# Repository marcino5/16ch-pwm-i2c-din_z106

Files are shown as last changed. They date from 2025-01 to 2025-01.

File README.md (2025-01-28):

# PCB 16xPWM i2c
This repository contains KiCAD files. This is an expansion module containing 16 PWM 12-24V outputs. The circuit consists of 16 N-Channel MOSFETs with a load capacity of 10A per channel controlled by a 12-bit LED controller PCA9685PW with an I2C interface. The circuit is not adapted to the maximum current, and for higher currents it is necessary to tin the exposed plus path. In my home configuration with ESPHome it works with 4 meter LED strips per channel and I did not observe any heating of the paths.

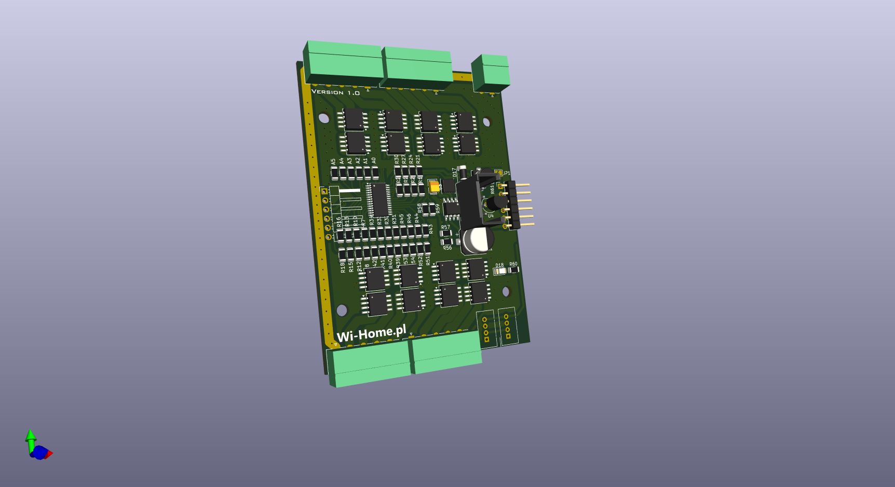
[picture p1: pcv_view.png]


The PCB is designed to fit in a commonly available DIN rail housing.

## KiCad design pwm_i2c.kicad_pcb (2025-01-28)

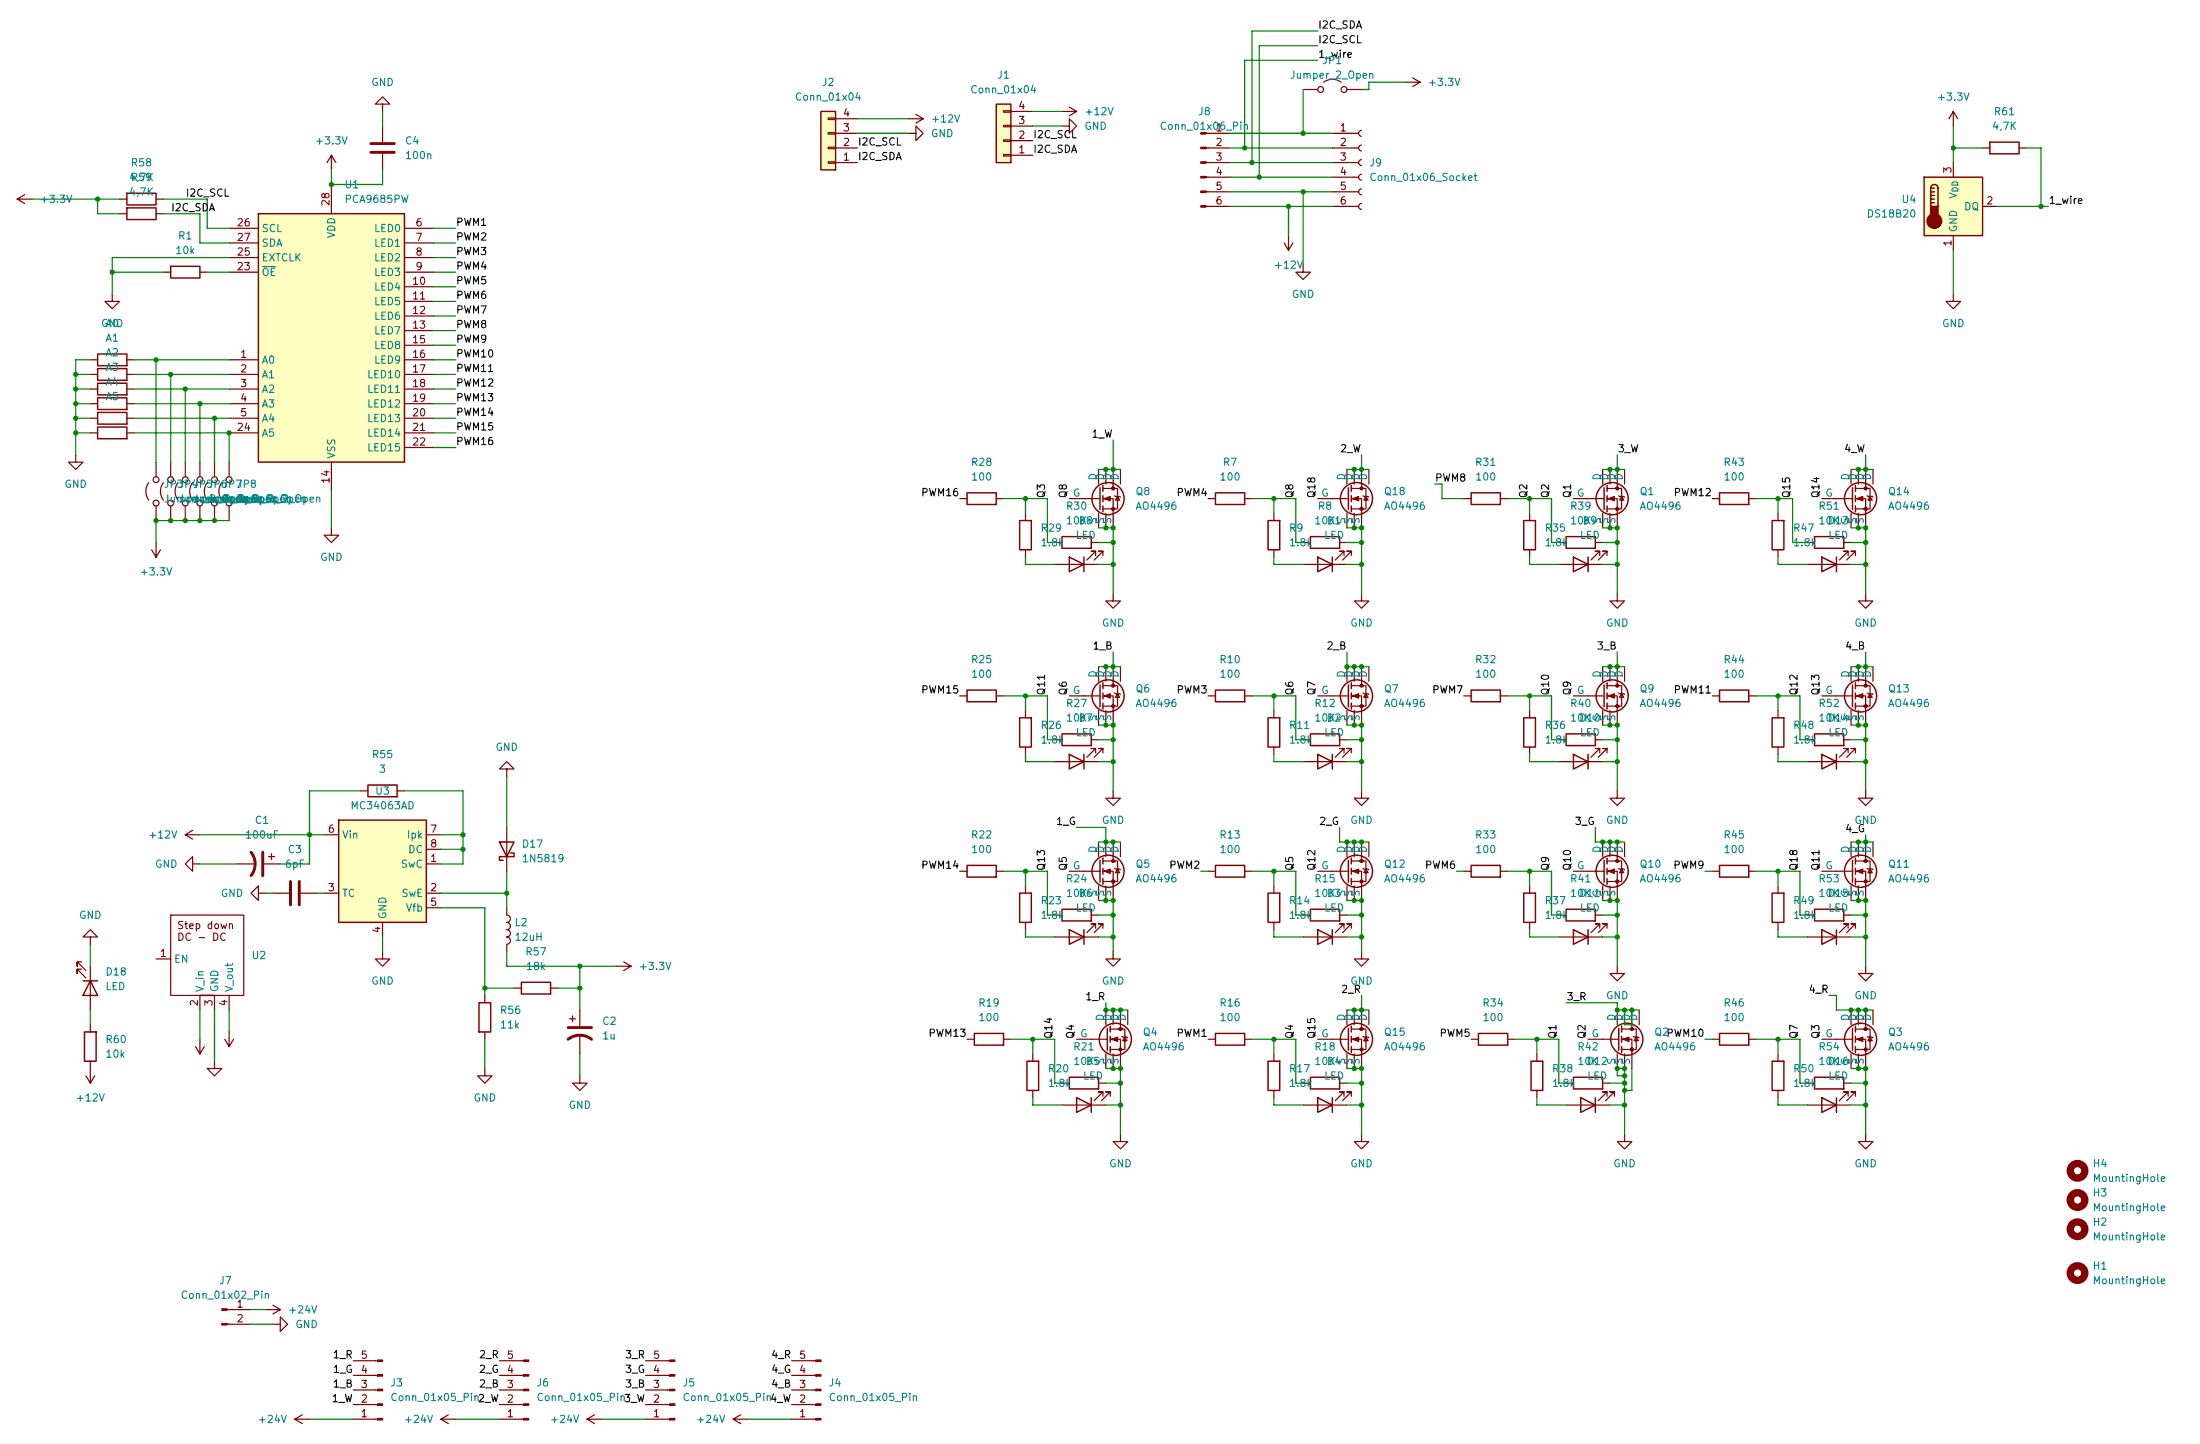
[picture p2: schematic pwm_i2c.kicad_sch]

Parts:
A0, A1, A2, A3, A4, A5: R_1206_3216Metric
C1: 100uF; CP_Elec_8x6.9
C2: 1u; CP_Elec_5x5.3
C3: 6pF; CP_EIA-3528-15_AVX-H
C4: 100n; C_1206_3216Metric_Pad1.33x1.80mm_HandSolder
D1, D2, D3, D4, D5, D6, D7, D8, D9, D10, D11, D12, D13, D14, D15, D16: LED; LED_1206_3216Metric
D17: 1N5819; D_MELF
D18: LED; LED_1206_3216Metric_Pad1.42x1.75mm_HandSolder
H1, H2, H3, H4: MountingHole; MountingHole_3.2mm_M3_ISO7380
J1, J2: Conn_01x04; NS-Tech_Grove_1x04_P2mm_Vertical
J3, J4, J5, J6: Conn_01x05_Pin; PhoenixContact_MC_1,5_5-G-3.81_1x05_P3.81mm_Horizontal
J7: Conn_01x02_Pin; PhoenixContact_MC_1,5_2-G-3.81_1x02_P3.81mm_Horizontal
J8: Conn_01x06_Pin; PinHeader_1x06_P2.54mm_Horizontal
J9: Conn_01x06_Socket; PinHeader_1x06_P2.54mm_Horizontal
JP1, JP3, JP4, JP5, JP6, JP7, JP8: Jumper_2_Open; SolderJumper-2_P1.3mm_Open_TrianglePad1.0x1.5mm
L2: 12uH; L_Changjiang_FNR4010S
Q1, Q2, Q3, Q4, Q5, Q6, Q7, Q8, Q9, Q10, Q11, Q12, Q13, Q14, Q15, Q18: AO4496; SO-8_5.3x6.2mm_P1.27mm
R1, R60: 10k; R_1206_3216Metric
R7, R10, R13, R16, R19, R22, R25, R28, R31, R32, R33, R34, R43, R44, R45, R46: 100; R_1206_3216Metric
R8, R12, R15, R18, R21, R24, R27, R30, R39, R40, R41, R42, R51, R52, R53, R54: 10K; R_1206_3216Metric
R9, R11, R14, R17, R20, R23, R29, R35, R36, R37, R38, R47, R48, R49, R50: 1.8k; R_1206_3216Metric
R26: 1.8k; R_1206_3216Metric_Pad1.30x1.75mm_HandSolder
R55: 3; R_1206_3216Metric
R56: 11k; R_1206_3216Metric
R57: 18k; R_1206_3216Metric
R58, R59, R61: 4,7K; R_1206_3216Metric
U1: PCA9685PW; TSSOP-28_4.4x9.7mm_P0.65mm
U2: Stocko_MKS_1654-6-0-404_1x4_P2.50mm_Vertical
U3: MC34063AD; SOIC-8_3.9x4.9mm_P1.27mm
U4: DS18B20; TO-92_Inline

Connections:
+3.3V: C2.1, C4.2, JP1.2 (B), JP3.1 (A), JP4.1 (A), JP5.1 (A), JP6.1 (A), JP7.1 (A), JP8.1 (A), L2.2, R57.2, R58.2, R59.2, R61.2, U1.28 (VDD), U2.4 (V_out), U4.3 (V_{DD})
+12V: C1.1, J1.4, J2.4, J8.6, J9.6, R55.1, R60.1, U2.2 (V_in), U3.6 (Vin)
+24V: J3.1, J4.1, J5.1, J6.1, J7.1
/1_B: J3.3, Q6.5 (D), Q6.6 (D), Q6.7 (D), Q6.8 (D)
/1_G: J3.4, Q5.5 (D), Q5.6 (D), Q5.7 (D), Q5.8 (D)
/1_R: J3.5, Q4.5 (D), Q4.6 (D), Q4.7 (D), Q4.8 (D)
/1_W: J3.2, Q8.5 (D), Q8.6 (D), Q8.7 (D), Q8.8 (D)
/1_wire: J8.2, J9.2, R61.1, U4.2 (DQ)
/2_B: J6.3, Q7.5 (D), Q7.6 (D), Q7.7 (D), Q7.8 (D)
/2_G: J6.4, Q12.5 (D), Q12.6 (D), Q12.7 (D), Q12.8 (D)
/2_R: J6.5, Q15.5 (D), Q15.6 (D), Q15.7 (D), Q15.8 (D)
/2_W: J6.2, Q18.5 (D), Q18.6 (D), Q18.7 (D), Q18.8 (D)
/3_B: J5.3, Q9.5 (D), Q9.6 (D), Q9.7 (D), Q9.8 (D)
/3_G: J5.4, Q10.5 (D), Q10.6 (D), Q10.7 (D), Q10.8 (D)
/3_R: J5.5, Q2.5 (D), Q2.6 (D), Q2.7 (D), Q2.8 (D)
/3_W: J5.2, Q1.5 (D), Q1.6 (D), Q1.7 (D), Q1.8 (D)
/4_B: J4.3, Q13.5 (D), Q13.6 (D), Q13.7 (D), Q13.8 (D)
/4_G: J4.4, Q11.5 (D), Q11.6 (D), Q11.7 (D), Q11.8 (D)
/4_R: J4.5, Q3.5 (D), Q3.6 (D), Q3.7 (D), Q3.8 (D)
/4_W: J4.2, Q14.5 (D), Q14.6 (D), Q14.7 (D), Q14.8 (D)
/I2C_SCL: J1.2, J2.2, J8.4, J9.4, R58.1, U1.26 (SCL)
/I2C_SDA: J1.1, J2.1, J8.3, J9.3, R59.1, U1.27 (SDA)
/PWM1: R16.1, U1.6 (LED0)
/PWM2: R13.1, U1.7 (LED1)
/PWM3: R10.1, U1.8 (LED2)
/PWM4: R7.1, U1.9 (LED3)
/PWM5: R34.1, U1.10 (LED4)
/PWM6: R33.1, U1.11 (LED5)
/PWM7: R32.1, U1.12 (LED6)
/PWM8: R31.1, U1.13 (LED7)
/PWM9: R45.1, U1.15 (LED8)
/PWM10: R46.1, U1.16 (LED9)
/PWM11: R44.1, U1.17 (LED10)
/PWM12: R43.1, U1.18 (LED11)
/PWM13: R19.1, U1.19 (LED12)
/PWM14: R22.1, U1.20 (LED13)
/PWM15: R25.1, U1.21 (LED14)
/PWM16: R28.1, U1.22 (LED15)
/Q1: Q1.4 (G), R34.2, R38.2, R42.1
/Q2: Q2.4 (G), R31.2, R35.2, R39.1
/Q3: Q3.4 (G), R28.2, R29.2, R30.1
/Q4: Q4.4 (G), R16.2, R17.2, R18.1
/Q5: Q5.4 (G), R13.2, R14.2, R15.1
/Q6: Q6.4 (G), R10.2, R11.2, R12.1
/Q7: Q7.4 (G), R46.2, R50.2, R54.1
/Q8: Q8.4 (G), R7.2, R8.1, R9.2
/Q9: Q9.4 (G), R33.2, R37.2, R41.1
/Q10: Q10.4 (G), R32.2, R36.2, R40.1
/Q11: Q11.4 (G), R25.2, R26.2, R27.1
/Q12: Q12.4 (G), R44.2, R48.2, R52.1
/Q13: Q13.4 (G), R22.2, R23.2, R24.1
/Q14: Q14.4 (G), R19.2, R20.2, R21.1
/Q15: Q15.4 (G), R43.2, R47.2, R51.1
/Q18: Q18.4 (G), R45.2, R49.2, R53.1
GND: A0.1, A1.1, A2.1, A3.1, A4.1, A5.1, C1.2, C2.2, C3.2, C4.1, D1.1 (K), D2.1 (K), D3.1 (K), D4.1 (K), D5.1 (K), D6.1 (K), D7.1 (K), D8.1 (K), D9.1 (K), D10.1 (K), D11.1 (K), D12.1 (K), D13.1 (K), D14.1 (K), D15.1 (K), D16.1 (K), D17.2 (A), D18.1 (K), J1.3, J2.3, J7.2, J8.5, J9.5, Q1.1 (S), Q1.2 (S), Q1.3 (S), Q2.1 (S), Q2.2 (S), Q2.3 (S), Q3.1 (S), Q3.2 (S), Q3.3 (S), Q4.1 (S), Q4.2 (S), Q4.3 (S), Q5.1 (S), Q5.2 (S), Q5.3 (S), Q6.1 (S), Q6.2 (S), Q6.3 (S), Q7.1 (S), Q7.2 (S), Q7.3 (S), Q8.1 (S), Q8.2 (S), Q8.3 (S), Q9.1 (S), Q9.2 (S), Q9.3 (S), Q10.1 (S), Q10.2 (S), Q10.3 (S), Q11.1 (S), Q11.2 (S), Q11.3 (S), Q12.1 (S), Q12.2 (S), Q12.3 (S), Q13.1 (S), Q13.2 (S), Q13.3 (S), Q14.1 (S), Q14.2 (S), Q14.3 (S), Q15.1 (S), Q15.2 (S), Q15.3 (S), Q18.1 (S), Q18.2 (S), Q18.3 (S), R1.2, R8.2, R12.2, R15.2, R18.2, R21.2, R24.2, R27.2, R30.2, R39.2, R40.2, R41.2, R42.2, R51.2, R52.2, R53.2, R54.2, R56.2, U1.14 (VSS), U1.25 (EXTCLK), U2.3 (GND), U3.4 (GND), U4.1 (GND)
unnamed: D1.2 (A), R9.1
unnamed: D2.2 (A), R11.1
unnamed: D3.2 (A), R14.1
unnamed: D4.2 (A), R17.1
unnamed: D5.2 (A), R20.1
unnamed: D6.2 (A), R23.1
unnamed: D7.2 (A), R26.1
unnamed: D8.2 (A), R29.1
unnamed: D9.2 (A), R35.1
unnamed: D10.2 (A), R36.1
unnamed: D11.2 (A), R37.1
unnamed: D12.2 (A), R38.1
unnamed: D13.2 (A), R47.1
unnamed: D14.2 (A), R48.1
unnamed: D15.2 (A), R49.1
unnamed: D16.2 (A), R50.1
unnamed: D17.1 (K), L2.1, U3.2 (SwE)
unnamed: D18.2 (A), R60.2
unnamed: J8.1, J9.1, JP1.1 (A)
unnamed: A0.2, JP3.2 (B), U1.1 (A0)
unnamed: A1.2, JP4.2 (B), U1.2 (A1)
unnamed: A2.2, JP5.2 (B), U1.3 (A2)
unnamed: A3.2, JP6.2 (B), U1.4 (A3)
unnamed: A4.2, JP7.2 (B), U1.5 (A4)
unnamed: A5.2, JP8.2 (B), U1.24 (A5)
unnamed: R1.1, U1.23 (~OE)
unnamed: R55.2, U3.1 (SwC), U3.7 (Ipk), U3.8 (DC)
unnamed: C3.1, U3.3 (TC)
unnamed: R56.1, R57.1, U3.5 (Vfb)

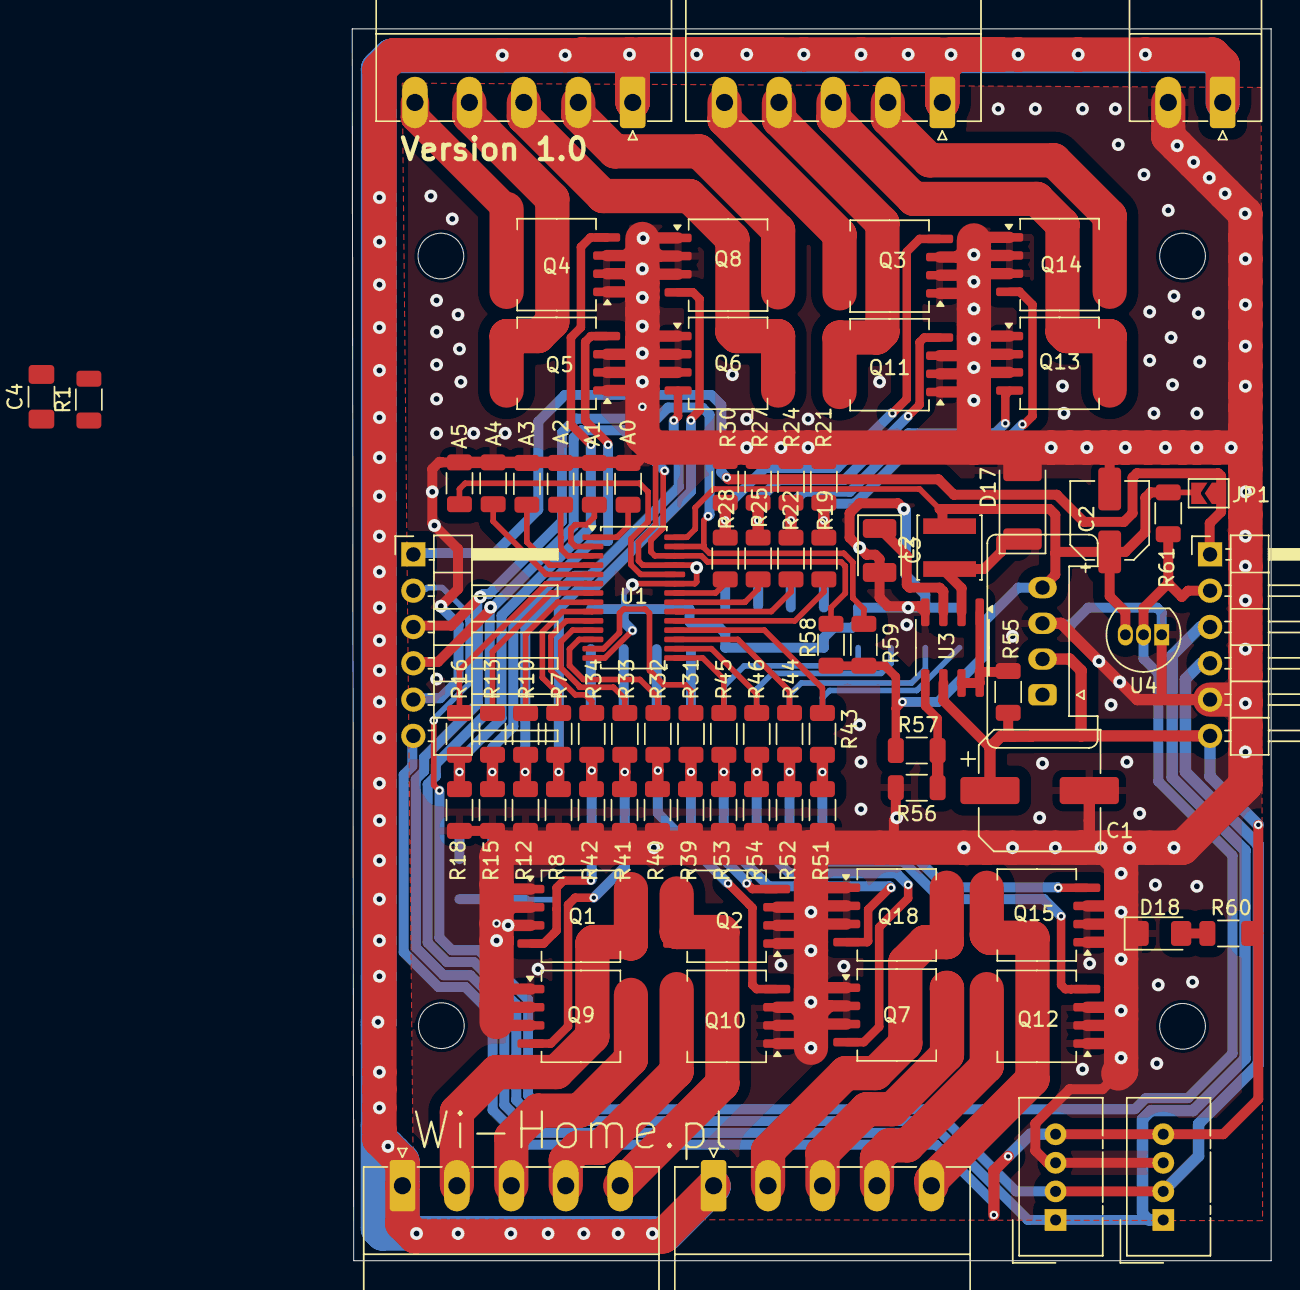
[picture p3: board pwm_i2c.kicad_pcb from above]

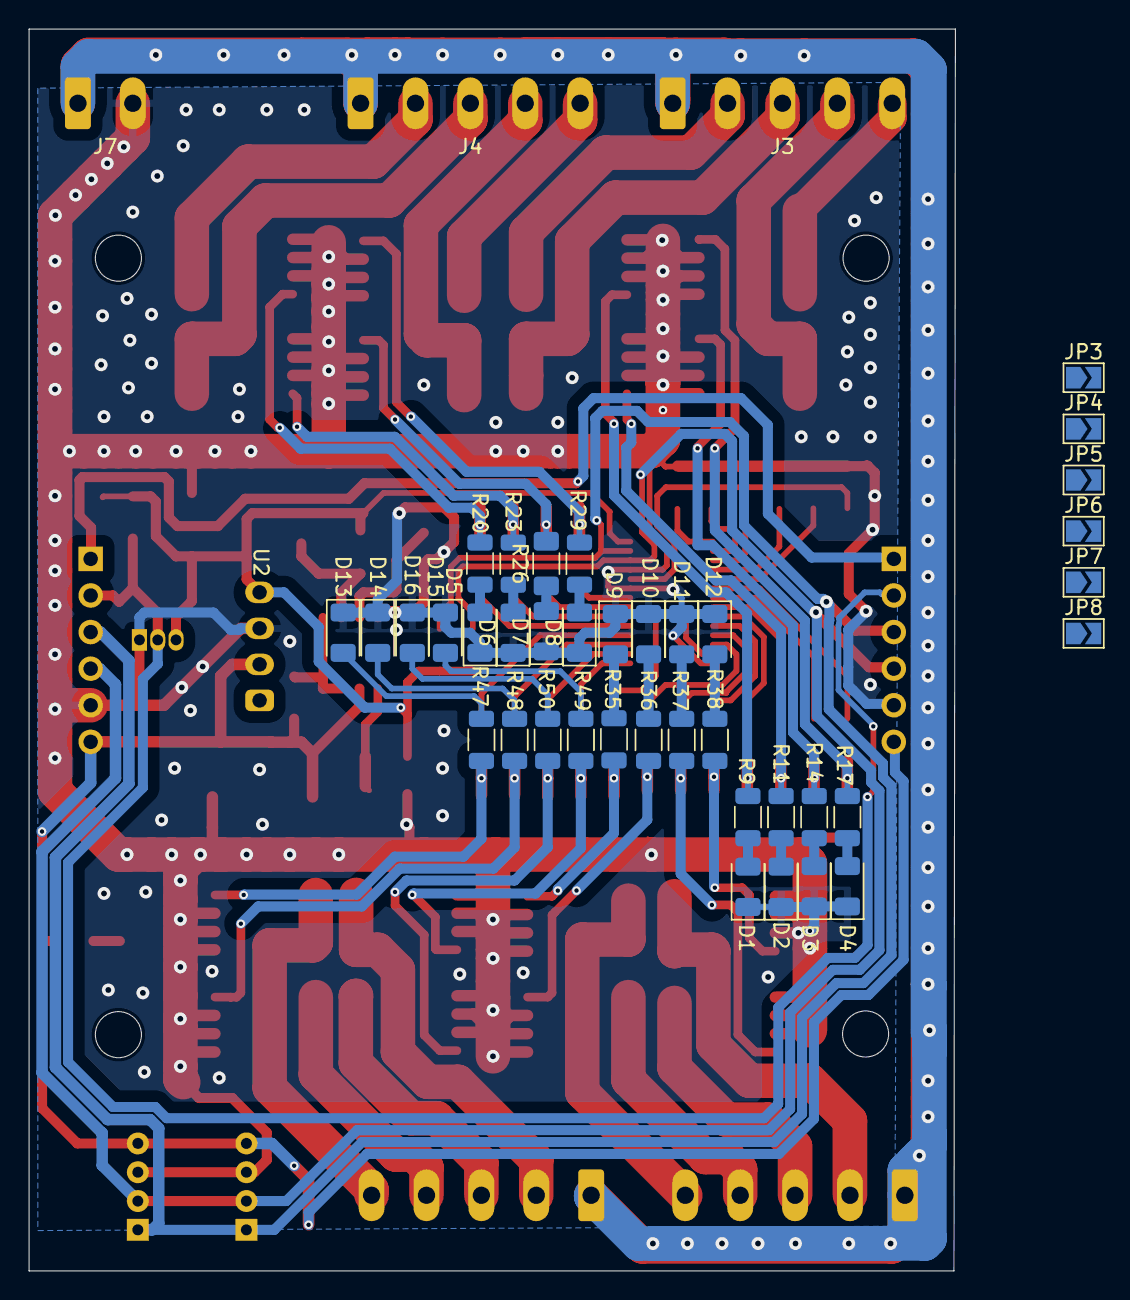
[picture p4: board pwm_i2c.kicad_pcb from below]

Board: 4 copper layers, 64.3 x 86.2 mm, 125 parts (38 on the bottom side), 84 nets.
